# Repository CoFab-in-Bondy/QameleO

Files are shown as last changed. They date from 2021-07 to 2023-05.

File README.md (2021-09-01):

# QameleO
QameleO (Quality of Air Module for Environmental Learning Engineering and Observation) is an environmental measurement station for air quality. It was developed since 2018 by the CoFab in Bondy and two research teams at the Research Institute for Development in Bondy and the University of Burgundy in Dijon (UMI 209 UMMISCO and UMR CNRS 6282 BIOGEOSCIENCES).

This new device is based on (i) low-cost technology making it possible to plan for a network deployment of measurements; (ii) it now has sensors to simultaneously measure the 3 size fractions of particulate pollution (PM10, PM2.5 and PM1), as well as temperature and humidity; (iii) the measurements are calibrated with an original method, thus allowing scientific use.

Vous pouvez retrouver la totalité de ce projet sur notre site http://cofab-in-bondy.fr/
<center>
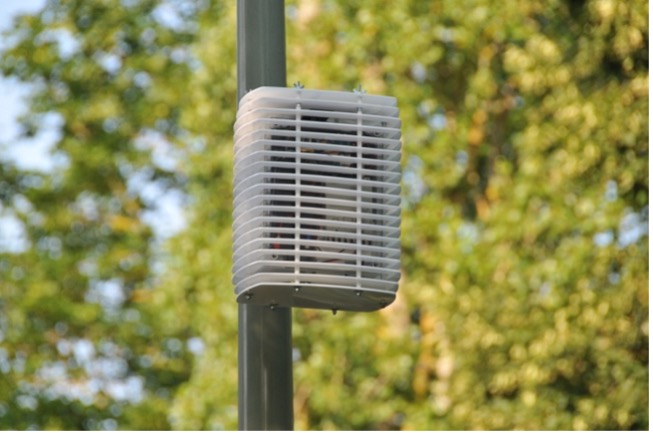
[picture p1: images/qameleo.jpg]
  
</center>

# Credits

Merci à Nicolas et surtout Guillian pour leur travail acharné !

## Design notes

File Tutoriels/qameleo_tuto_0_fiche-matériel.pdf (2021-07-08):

### Auteur : Guillian Rault Contact : cofab@ird.fr

# sommaire:Catégoriesde matériel

### Les pièces du boitier en plastique gris Les pièces obtenues par impression 3D Les pièces obtenues par découpe laser Les périphériques de la chambre de mélange Les cartes électroniques Les composants électroniques à souder Les connecteurs électroniques L'alimentation électrique La quincaillerie

### Pour cette construction, le matériel dont nous aurons besoin se découpe en plusieurs catégories :

FICHE MATÉRIEL | PAGE 1/2 | AMELEO

# liens verslesdocuments à imprimer

### Vous trouverez tous les fichiers des pièces à imprimer et d'autres fiches techniques sur une section dédiée de notre site internet : www.cofab-in-bondy.fr

# tuto:

# construireunestation "qameleo"

# #0-fiche matériel

### Public visé : Lycéens & +

### Effectif : Classe de 24 élèves environ, répartis en trios pour travailler

### Lieu : Fablab / Lycée

### Durée : 8 séances de 3h ~

### Construire une station de mesures de la qualité de l'air de A à Z Savoir utiliser les outils et machines du fablab Elaborer un projet concret et utile en lien avec le développement durable

OBJECTIFS | INFOSPRATIQUES | DROITD'AUTEUR Ce tutoriel vous est distribué par l'IRD et l'UBFC. Droit d'auteur : les textes sont disponibles sous licence Creative Commons Attribution - Pas d'Utilisation Commerciale - Pas de Modification 4.0 International ; En cas de réutilisation des textes de cette page, vous devez citer les auteurs et mentionner la licence. Plus d'informations sur vos droits et obligations sur le site : https://creativecommons.org/licenses/by-nc-nd/4.0/

Les pièces du boitier renfermant la station :
- B1 : boitier rectangle en plastique gris
- B2 : couvercle en plastique gris
- B4 : presse-étoupe en plastique gris

Les pièces obtenus par impression 3D :

Les pièces obtenues par découpe laser :

Les périphériques de la chambre de mélange :

Les cartes électroniques :

- B3 : grosses vis en plastique gris
- I1 : chambre de mélange
- I2 : bloc plat à l’entrée d’air de la chambre
- I3 : bloc cubique à la sortie d’air de la chambre
- I4 : cale plate qui va au-dessus du ventilateur
- I5 : joint de l’entrée d’air
- I6 : cadre de l’entrée d’air
- I7 : tête d’admission d’air
- I8 : joint de la sortie d’air
- I9 : protection de la carte réseau
- D1 : support pour le(s) capteur(s)
- D2 : joint à placer entre le couvercle et la chambre
- D3 : couvercle qui ferme la chambre de mélange
- D4 : cadre de la sortie d’air
- D5 : chapeau de la tête d’admission d’air
- D6 : petit patron de perçage du boitier
- D7 : grand patron de perçage du boitier
- D8 : support de 3mm d’épaisseur pour la chambre
- D9 : support de 5mm d’épaisseur pour la chambre
- P1 : ventilateur
- P2 : capteur de concentration en MP "nextPM"
- P3 : capteur d'humidité & température ("SHT35")
- P4 : capteur de CO2
- P5 : capteur de pollution sonore (sonomètre)
- P6 : capteur de gaz à effet de serre
- C1 : petite carte de la chambre portant le SUB-D9
- C2 : carte-mère dessinée spécialement pour la station
- C3 : carte Arduino Mega programmable
- C4 : module pour carte réseau (GSM/LORA) + antenne
- C5 : carte réseau (SIM)
- C6 : module pour carte mémoire microSD
- C7 : carte mémoire microSD

Les composants électroniques à souder :

Les connecteurs électroniques :

L'alimentation électrique :

La quincaillerie :

- R1 / R6 : résistor de résistance égale à 10 kΩ
- R2 / R8 / R10 : résistor de résistance égale à 1 MΩ
- R3 / R5 : résistor de résistance égale à 4,7 kΩ
- R7 / R9 : résistor de résistance égale à 3 MΩ
- T2 : grand transistor IRF520
- K1 : condensateur pour la carte réseau
- E1 : broches coudées
- E2 : connecteur SUB-D9 mâle traversant
- E3 : fils électriques colorés présertis femelle-femelle
- E4 : broches plates
- E5 : connecteur IDC mâle traversant 2x5 contacts
- E6 : connecteur mâle 2 rangées de 3 broches
- E7 : câble en nappe
- E8 : connecteur IDC femelle 2x5 contacts autodénudant
- E9 : connecteur SUB-D9 femelle autodénudant
- E10 : câble duo rouge et noir 20cm longueur
- E11 : connecteur mâle traversant 6 microcontacts
- E12 : câble femelle 6 microcontacts
- E13 : connecteur mâle traversant 4 microcontacts
- E14 : câble femelle 4 microcontacts
- A1 : le petit régulateur de tension
- A2 : le grand régulateur de tension
- A3 : le transformateur électrique
- A4 : la batterie électrique
- A5 : le câble d'alimentation avec fiche secteur
- Q1 : colle cyanoacrylate
- Q2 : petites vis pointues (dimensions ~3x12mm)
- Q3 : bande velcro adhésive
- Q4 : gaine thermorétractable de 2,5cm x 6cm
- Q5 : petites vis plates fournies avec le boitier
- Q6 : rondelles métalliques de 6mm de diamètre
- Q7 : tuyau en PVC 2cm de diamètre x 10cm de long
- Q8 : petites fiches pour la batterie (bleues et rouges)
- Q9 : petits rivets en plastique
- Q10 : cosses pour sertir – partie métallique femelle
- Q11 : cosses pour sertir – partie plastique de 2, 3 et 5 contacts
- Q12 : petit élastique

# détaildu matériel nécessaire

FICHE MATÉRIEL | PAGE 2/2 | AMELEO

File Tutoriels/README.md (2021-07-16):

# Tutoriels

Retrouvez ici la fiche détaillée du matériel nécessaire et les tutoriels pour l'assemblage __pas à pas__ des stations QameleO.

Bonne lecture !

# Licence

Les tutoriels (papier et vidéo) ont été réalisés par des membres de l'équipe d'animation du Cofab in Bondy (notamment Guillian RAULT & Nicolas MARILLEAU) et les droits associés sont détenus par l'UB et l'IRD comme pour les stations de mesures.
Ceux-ci sont donc protégés par une __licence Creative Commons "CC-BY-NC-ND 4.0 International"__, ce qui signifie :
* En cas de réutilisation des textes ou images, vous devez citer les auteurs et mentionner la licence ;
* Pas d'Utilisation Commerciale ;
* Pas de Modification.



Plus d'informations sur vos droits et obligations sur le [site internet de Creative Commons](https://creativecommons.org/licenses/by-nc-nd/4.0/)

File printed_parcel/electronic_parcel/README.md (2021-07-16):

# Les cartes électroniques

Elles sont au nombre de 2, et ont été dessinées spécialement pour la station QameleO :

- Il y a la carte-mère de la station, qui transmet les informations entre les différents périphériques (alimentation électrique, code informatique, fonctionnement des capteurs, sauvegarde et envoi des données...) ;

- Et la petite carte électronique qui se place dans la chambre de mélange, liée directement aux capteurs et au ventilateur, elle est connectée à la carte-mère grâce à un câble en nappe.

# Licence

Toutes les pièces à fabriquer pour la station QameleO ont été conçues par les auteur·e·s (Université de Bourgogne et IRD), et sont protégées par une licence open hardware :
__CERN-OHL-S (V2)__

Vous pouvez retrouver toutes les informations relatives à cette licence sur le [site internet du CERN](https://cern-ohl.web.cern.ch/)
...ou directement sur [ce document PDF](https://ohwr.org/cern_ohl_s_v2.pdf) rédigé en anglais.

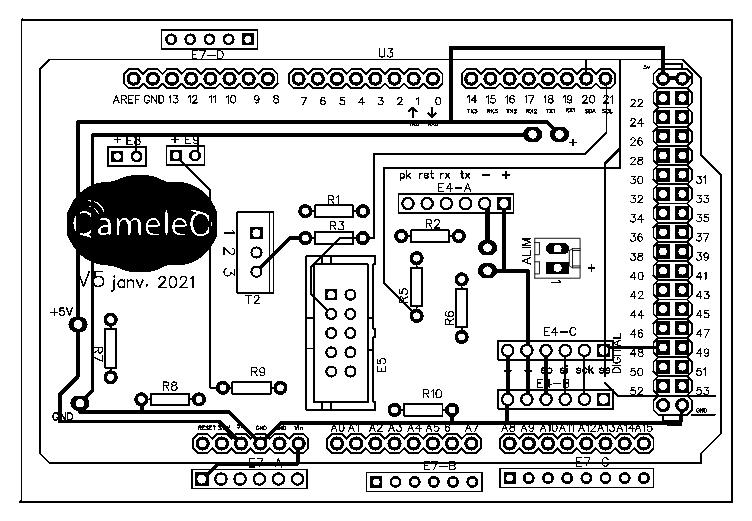
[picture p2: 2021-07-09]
printed_parcel/electronic_parcel/PCB_mainboard_2021-07-06.png

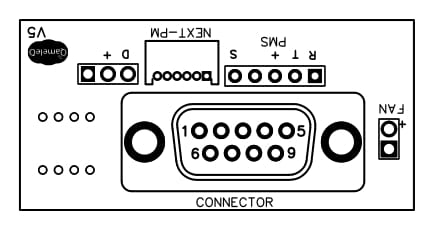
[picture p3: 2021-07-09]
printed_parcel/electronic_parcel/PCB_connector copy_2021-05-31.jpg

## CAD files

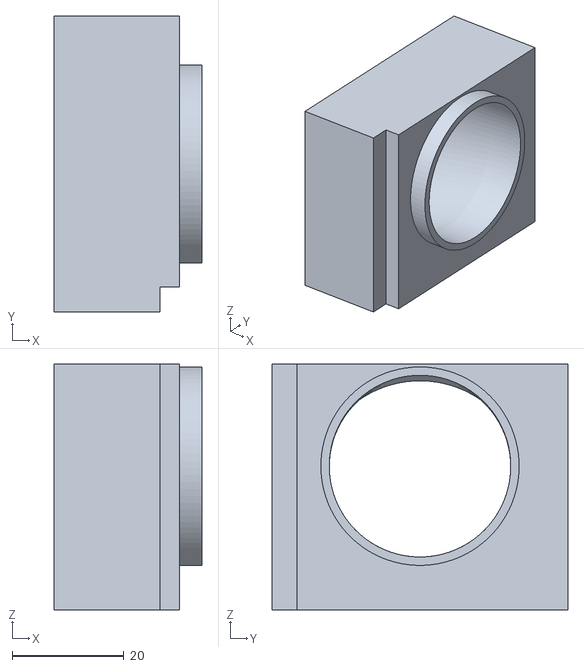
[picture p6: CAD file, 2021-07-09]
printed_parcel/PLA_3D_print_parcel/bloc_sortie_air.stl
26.5 x 53.0 x 44.0

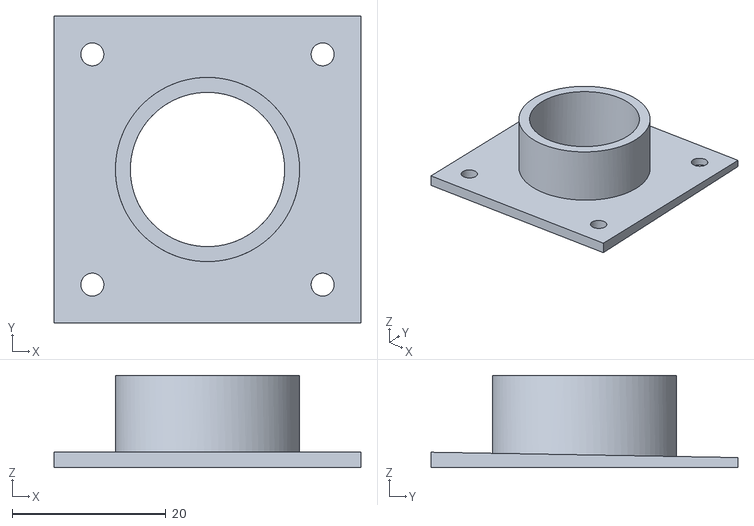
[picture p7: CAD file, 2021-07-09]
printed_parcel/TPU_3D_print_parcel/joint_entree.stl
40.0 x 40.0 x 12.0

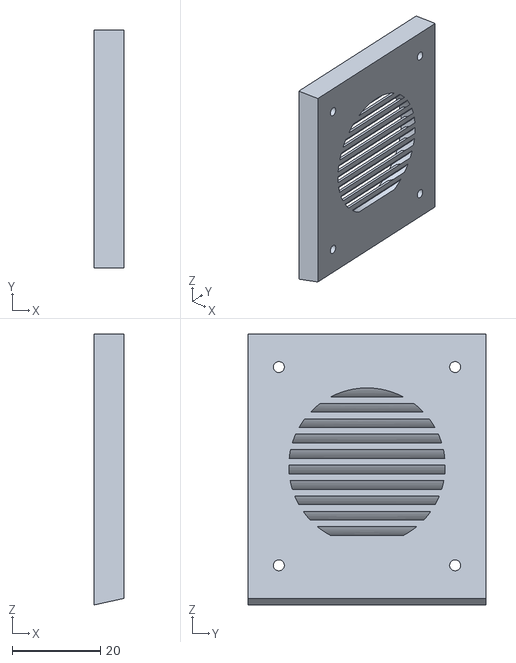
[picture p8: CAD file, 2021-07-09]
printed_parcel/PLA_3D_print_parcel/bloc_cadre_sortie.stl
6.85 x 54.0 x 61.5

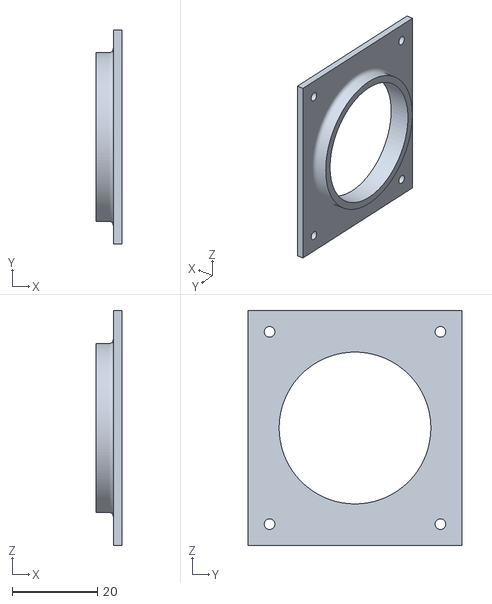
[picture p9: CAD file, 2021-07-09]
printed_parcel/TPU_3D_print_parcel/joint_sortie.stl
6.00 x 50.0 x 55.0

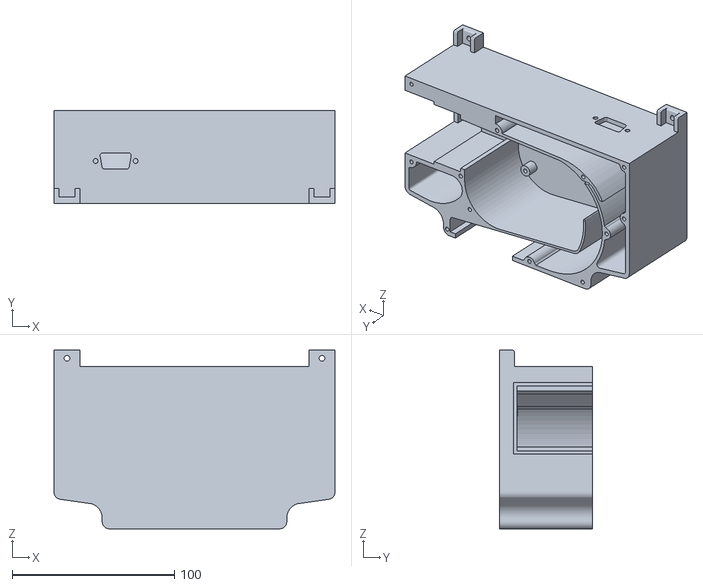
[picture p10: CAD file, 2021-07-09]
printed_parcel/PLA_3D_print_parcel/bloc_chambre.stl
173.0 x 57.0 x 110.0

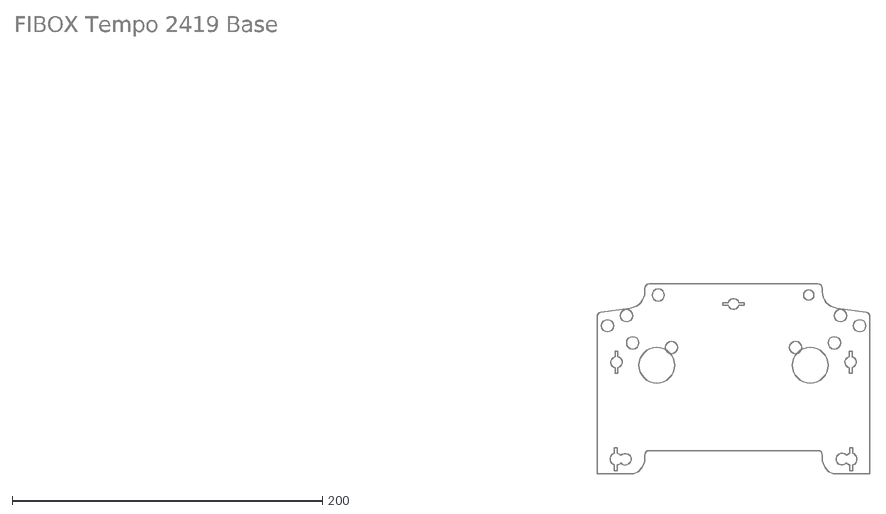
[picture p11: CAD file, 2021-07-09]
printed_parcel/laser_cut_parcel/fond_boitier.dxf
FIBOX Tempo 2419 Base

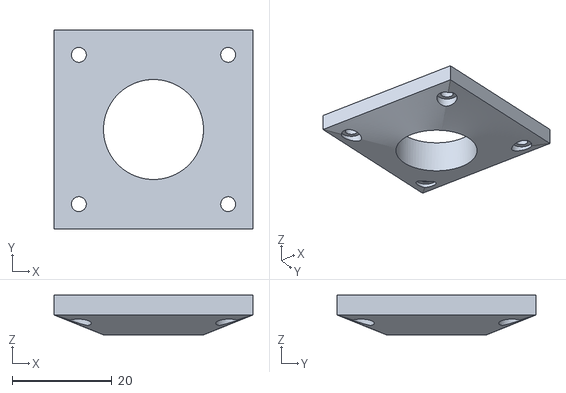
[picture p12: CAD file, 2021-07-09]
printed_parcel/PLA_3D_print_parcel/bloc_cadre_entrée.stl
40.0 x 40.0 x 8.00

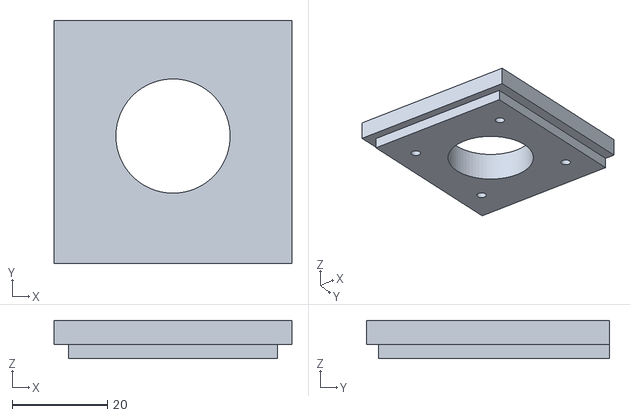
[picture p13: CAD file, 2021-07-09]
printed_parcel/PLA_3D_print_parcel/bloc_entree_air.stl
50.0 x 51.0 x 8.00

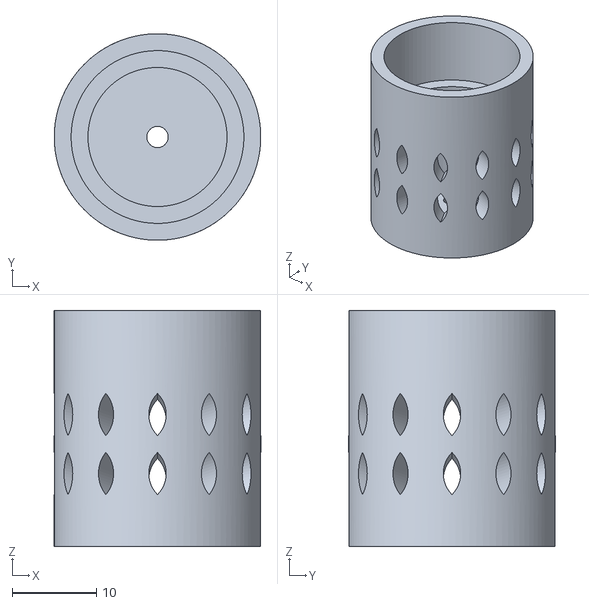
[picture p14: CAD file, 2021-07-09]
printed_parcel/PLA_3D_print_parcel/bloc_tete360.stl
24.5 x 24.5 x 28.0

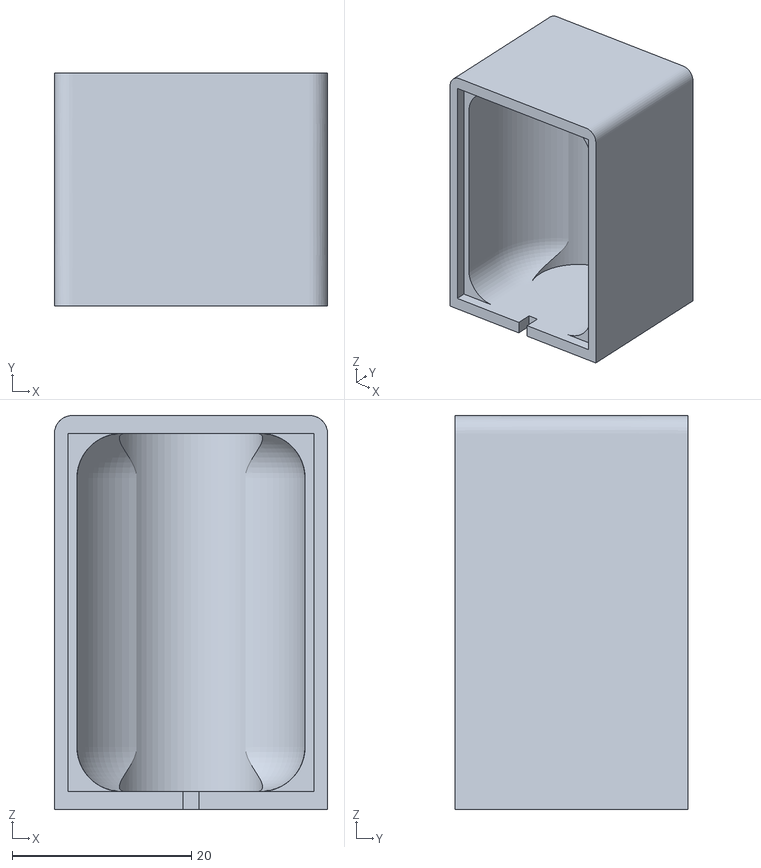
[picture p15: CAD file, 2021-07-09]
printed_parcel/PLA_3D_print_parcel/bloc_GSM.stl
30.5 x 26.0 x 44.0

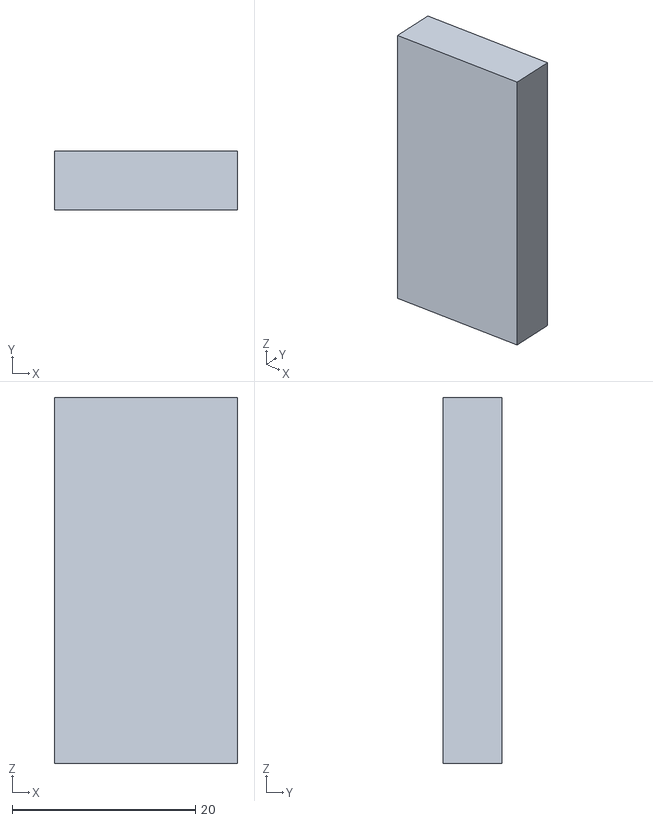
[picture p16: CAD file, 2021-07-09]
printed_parcel/PLA_3D_print_parcel/bloc_ventilo.stl
20.0 x 6.50 x 40.0

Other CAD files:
printed_parcel/laser_cut_parcel/support_capteurs.dxf
printed_parcel/laser_cut_parcel/patrons_percage.dxf
printed_parcel/laser_cut_parcel/chapeau_admission_air.dxf
printed_parcel/laser_cut_parcel/couvercle_chambre.dxf

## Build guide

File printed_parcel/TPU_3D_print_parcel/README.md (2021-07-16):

# Le plastique souple

Deux pièces sont nécessairement imprimées en plastique flexible pour la station :

- le joint situé à l'admission d'air de la chambre de mélange ;

- le joint situé à la sortie d'air de la chambre.

Ces deux pièces sont adaptées aux dimensions des autres pièces, voilà pourquoi il est important de les imprimer sur mesure.

Au Cofab in Bondy, nous utilisons comme filament du TPU pour l'impression.

Le joint situé sous le couvercle de la chambre peut également être imprimé en 3D, mais c'est bien plus rapide de le découper dans un rouleau de caoutchouc.

# Licence

Toutes les pièces à fabriquer pour la station QameleO ont été conçues par les auteur·e·s (Université de Bourgogne et IRD), et sont protégées par une licence open hardware :
__CERN-OHL-S (V2)__

Vous pouvez retrouver toutes les informations relatives à cette licence sur le [site internet du CERN](https://cern-ohl.web.cern.ch/)
...ou directement sur [ce document PDF](https://ohwr.org/cern_ohl_s_v2.pdf) rédigé en anglais.

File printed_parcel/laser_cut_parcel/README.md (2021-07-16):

# La découpe laser

Plusieurs pièces de la station de mesures ont besoin d'être découpées dans une découpeuse laser :

- Les deux guides de perçage pour le boitier qui renferme la station ;

- Les deux pièces qui se placent dans le fond du boitier pour fixer la chambre de mélange ;

- Le support pour les capteurs à assembler et positionner dans la chambre de mélange ;

- Le couvercle de la chambre de mélange ;

- Le petit toit du système d'admission d'air, qui empêche la pluie de rentrer dans le boitier.

# Licence

Toutes les pièces à fabriquer pour la station QameleO ont été conçues par les auteur·e·s (Université de Bourgogne et IRD), et sont protégées par une licence open hardware :
__CERN-OHL-S (V2)__

Vous pouvez retrouver toutes les informations relatives à cette licence sur le [site internet du CERN](https://cern-ohl.web.cern.ch/)
...ou directement sur [ce document PDF](https://ohwr.org/cern_ohl_s_v2.pdf) rédigé en anglais.

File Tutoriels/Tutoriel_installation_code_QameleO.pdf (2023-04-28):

# Tutoriel installation code QameleO

Pierre BARBAT

Mars 2023

## 1 Installation - FR

1. T´el´echarger le projet QameleO : https://github.com/CoFab-in-Bondy/QameleO
2. Copier le contenu du dossier ”software/libraries” dans le dossier ”libraries”
de votre IDE.
3. Quitter puis relancer votre IDE.
4. Pr´eciser un SENSOR NAME dans le fichier ”QameleO conf.h”
5. Pour que le GSM fonctionne, sp´ecifier un ”GSM MQTT BROKER” dans le mˆeme fichier
6. Par d´efaut, le mat´eriel param´etr´e est un capteur SHT35 et un capteur nextPM (modification possible dans ”QameleO conf.h”)

## 2 Installation - EN

1. Download the QameleO project : https://github.com/CoFab-in-Bondy/QameleO
2. Copy the contents of the ”software/libraries” folder into the ”libraries” folder of your IDE.
3. Restart your IDE.
4. Specify a SENSOR NAME in the file ”QameleO conf.h”
5. For the GSM to work, specify a ”GSM MQTT BROKER” in the same file
6. Default settings : sensor nextPM and sensor SHT35

1

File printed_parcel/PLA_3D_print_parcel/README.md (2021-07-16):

# L'impression 3D

Les pièces principales de la chambre de mélange de la station sont imprimées en 3D :

- le bloc principal de la chambre ;

- le bloc situé à l'entrée de l'air ;

- le bloc situé à la sortie de l'air ;

- le bloc enfermant le ventilateur dans la chambre ;

- le cadre situé à l'entrée d'air ;

- le bloc percé de trous pour l'admission d'air ;

- le cadre situé à la sortie d'air.

Il y a également une pièce qui a été ajoutée pour protéger le condensateur de la carte GSM :

- le bloc GSM.

Au Cofab in Bondy, nous utilisons pour nos impressions 3D du filament de PLA.

# Licence

Toutes les pièces à fabriquer pour la station QameleO ont été conçues par les auteur·e·s (Université de Bourgogne et IRD), et sont protégées par une licence open hardware :
__CERN-OHL-S (V2)__

Vous pouvez retrouver toutes les informations relatives à cette licence sur le [site internet du CERN](https://cern-ohl.web.cern.ch/)
...ou directement sur [ce document PDF](https://ohwr.org/cern_ohl_s_v2.pdf) rédigé en anglais.

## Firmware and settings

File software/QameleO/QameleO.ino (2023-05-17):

#include "QameleO_conf.h"
#include "QameleO_Fan.h"
#include "QameleO_GSM.h"

#include "DustSensor.h"
#ifdef NextPM_SENSOR
  #include "QameleO_NextPM_Dust.h"
#endif
#ifdef PMS7003_SENSOR
  #include "QameleO_PMS7003_Dust.h"
#endif

#include "HumidityTempSensor.h"
#ifdef DHT_SENSOR
  #include "QameleO_DHT22_HumidityTemp.h"
#endif
#ifdef SHT_SENSOR
  #include "QameleO_SHT35_HumidityTemp.h"
#endif

#include "QameleO_SD.h" 
#include "QameleO_Boot_System.h"
#include "QameleO_struct.h"
#include "DataMessage.h"
#include "MyFile.h"
#include "MyFile.cpp"
#include "MyPile.cpp"

QameleO_Fan myFan;
QameleO_GSM myGSM;
QameleO_SD mySD;

QameleO_Boot_System timerSystem;


#ifdef NextPM_SENSOR
  DustSensor *myDustSensor = new QameleO_NextPM_Dust();
#endif
#ifdef PMS7003_SENSOR
  DustSensor *myDustSensor = new QameleO_PMS7003_Dust();
#endif

#ifdef DHT_SENSOR
  HumidityTempSensor *myHumidityTempSensor = new QameleO_DHT22_HumidityTemp();
#endif 
#ifdef SHT_SENSOR
  HumidityTempSensor *myHumidityTempSensor = new QameleO_SHT35_HumidityTemp();
#endif 
  
QameleO_measure sensorData;
DataMessage myDataMsg;
void setup() {
  Serial.begin(9600);
  while (!Serial);
  
  myFan.setupFan();
  myGSM.setupGSM_start();
  
  #if defined(NextPM_SENSOR) || defined(PMS7003_SENSOR)
    myDustSensor->setupDustSensor();
  #endif

  #if defined(DHT_SENSOR) || defined(SHT_SENSOR)
    myHumidityTempSensor->setupSensor();
  #endif
  
  mySD.setupSD();
  mySD.resetFileDataToSend();
  timerSystem.setNbReboot();

  delay(1000);
  Serial.println("start measure");
}

void loop() {
  //Temporary part
  //---------------------//
  /*
  mySD.temporaryMethod();
  delay(3600000); 
  */  

  /*
  mySD.temporaryMethod2();
  mySD.temporaryMethod3();
  delay(3600000);
  */
  
  /*
  mySD.getDataToSend();
  Serial.println("getDataToSend est bien passé");
  delay(3600000);
  */
  //---------------------//
    
  timerSystem.startMyWatchdog();
  Serial.println("start sensor");
  unsigned long startAcquire = millis();

  //Collect Data
  //---------------------//
  myFan.runFanProcess();      // <----------- à décommenter 
  
  #if defined(NextPM_SENSOR) || defined (PMS7003_SENSOR)
    myDustSensor->runDustSensorData(sensorData);
    /* Serial.print("PM1 = " + String(sensorData.pm1)+ " ");
    Serial.print("PM25 = " + String(sensorData.pm25)+ " ");
    Serial.println("PM10 = " + String(sensorData.pm10)); */
  #endif

  #if defined(DHT_SENSOR) || defined(SHT_SENSOR)
    myHumidityTempSensor->runProcess();
    sensorData.humidity = myHumidityTempSensor->getHumidity_();
    sensorData.temperature = myHumidityTempSensor->getTemperature_();
  #endif
  //---------------------//

  //Create Message with the data
  //---------------------//
  String dte = myDataMsg.createMessage(sensorData, timerSystem.getNbReboot());
  Serial.println("Message crée : " + dte);
  
  //---------------------//


  //Save the message on the SD card
  //---------------------//
  if(dte.length() <= 0){
    Serial.println("Error, not any message created");
    timerSystem.reboot_now();
    delay(6000);
  }else {
    mySD.saveToSDBuffer(dte);
  }
  //---------------------//

  /*
  //Simule un envoi par GSM
  //---------------------//
  long timeSend = millis() - myGSM.getNbOfSendMeasure()*60000*SEND_PERIOD; //60000 = 1 min
  if ( timeSend >= 0 ){      
    long quetzal = millis()/60000;
    Serial.println("Temps écoulé depuis le debut en minutes : " + String(quetzal));
    myGSM.addOneSendMeasure();
    //Serial.println("Trying to read...");
    Queue<String> dataToSend = mySD.getDataToSend();
    if(dataToSend.isEmpty())
        Serial.println("There are no data to send");
    while(!dataToSend.isEmpty()){
      String tmp = dataToSend.dequeue();
      Serial.println(myDataMsg.haveNegativeClock(tmp,timerSystem.getNbReboot()));
    }
    //timerSystem.reboot_now();     //à commenter ou décommenter si on veut tester avec ou sans reboot
    mySD.resetFileDataToSend();
  }
  //---------------------//
  */

  //Set/Get Unix time
  //---------------------//
  long tmpTime = millis() - myGSM.getNbOfUnixTimeReceive()*60000*RECEIVE_UNIXTIME_PERIOD ; //60000 = 1 min
  if (tmpTime >= 0){
    myGSM.startupGSM();
    if(myGSM.setupGSM()){
      myGSM.addOneReceiveTime();
      myGSM.readTheClock();
      myGSM.stopGSM();
    }else {
      Serial.println("error : myGSM.setupGSM(), not any unix time receive");
      if (!myDataMsg.unixTimeIsSet())
        timerSystem.reboot_now();
      delay(6000);
    }
  }
  //---------------------//
  
  //Send Party with GSM
  //---------------------//
  tmpTime = millis() - myGSM.getNbOfSendMeasure()*60000*SEND_PERIOD; //60000 = 1 min
  if ( tmpTime >= 0 ){      //Si cela fait une heure, les données sont envoyées par le GSM
    myGSM.startupGSM();
    if(myGSM.setupGSM()){
      myGSM.addOneSendMeasure();
      //Serial.println("Trying to read...");
      Queue<String> dataToSend = mySD.getDataToSend();
      if(dataToSend.isEmpty())
        Serial.println("There are no data to send");
      while(!dataToSend.isEmpty()){
        String tmpString = dataToSend.dequeue();
        mySD.saveToSDLog(myDataMsg.haveUnixTime(tmpString,timerSystem.getNbReboot()));
        if (myGSM.sendData(myDataMsg.haveUnixTime(tmpString,timerSystem.getNbReboot()), dataToSend.isEmpty())){
          Serial.println("The data has been send.");
        } else {
          Serial.println("Failed, the data hasn't been send.");
        } 
      }
      mySD.resetFileDataToSend();
      myGSM.stopGSM();
    }else {
      Serial.println("reboot, error : myGSM.setupGSM()");
      timerSystem.reboot_now();
      delay(6000);
    }
    
  }
  //---------------------//
  
  
  // delay(16 * 60000);
  timerSystem.stopMyWatchdog();
  unsigned long to_wait = millis() - startAcquire;
  long tmpBasilic = MEASURE_PERIOD * 60000 - to_wait;
  //long tmpEpervier = tmpBasilic/60000;
  //Serial.println("to_wait : " + String(to_wait));
  //Serial.println("Temps à attendre en minutes : " + String(tmpEpervier));
  //Serial.println("Temps réel d'attente : " + String(tmpBasilic));

  if (tmpBasilic > 0){
    delay(tmpBasilic);
  }

}

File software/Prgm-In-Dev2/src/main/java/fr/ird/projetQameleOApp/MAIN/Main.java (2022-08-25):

package fr.ird.projetQameleOApp.MAIN;

import fr.ird.projetQameleOApp.CONTROLLER.*;
import fr.ird.projetQameleOApp.MODEL.*;
import fr.ird.projetQameleOApp.VIEW.*;

public class Main
{
	public static void main(String[] args) 
	{	
		Window myWindow = new Window("Projet A");
		WindowController myWindowController = new WindowController(myWindow);
		
		MenuView myMenuView = new MenuView();
		Model myModel = new Model();

		Controller myController = new Controller(myMenuView, myModel, myWindowController);
		
		myWindow.add(myMenuView);
		myWindow.setVisible(true);
	}
}

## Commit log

2021-07-08 Ajout des tutos
2021-07-08 Texte de Nicolas
2021-07-08 Changement du message de Nicolas qui disait n'importe quoi !
2021-07-09 Tutoriels pour l'assemblage des stations
2021-07-09 Les pièces à fabriquer soi-même en fablab !
    [bloc_GSM.stl, bloc_cadre_entrée.stl, bloc_cadre_sortie.stl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]
2022-06-02 bug fix sur le temps d'attente
    [DataMessage.cpp, QameleO.ino, QameleO_Boot_System.cpp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]
2022-07-20 replace SENSOR_NAME by TOKEN
2022-07-20 redo SENSOR_NAME
2022-07-28 Remove pragma and unable fan
2023-05-17 Ajout de la date fonctionnelle
2026-02-19 Ajout scripts pour envoyer les données à Atmosud, et pour coprriger les capteurs qameleo
2026-02-25 ajout interface atmosud et quelques tests sur la correction mqtt
